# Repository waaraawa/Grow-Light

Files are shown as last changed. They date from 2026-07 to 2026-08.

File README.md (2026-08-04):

# Grow Light

A circular 12 V LED board designed for growing plants. The board uses a single-sided, 80 mm aluminum MCPCB with 20 red LEDs and 3 blue LEDs. A [medium Daiso aluminum makgeolli cup](https://www.daisomall.co.kr/pd/pdr/SCR_PDR_0001?pdNo=58656) serves as the heatsink and mechanical structure.

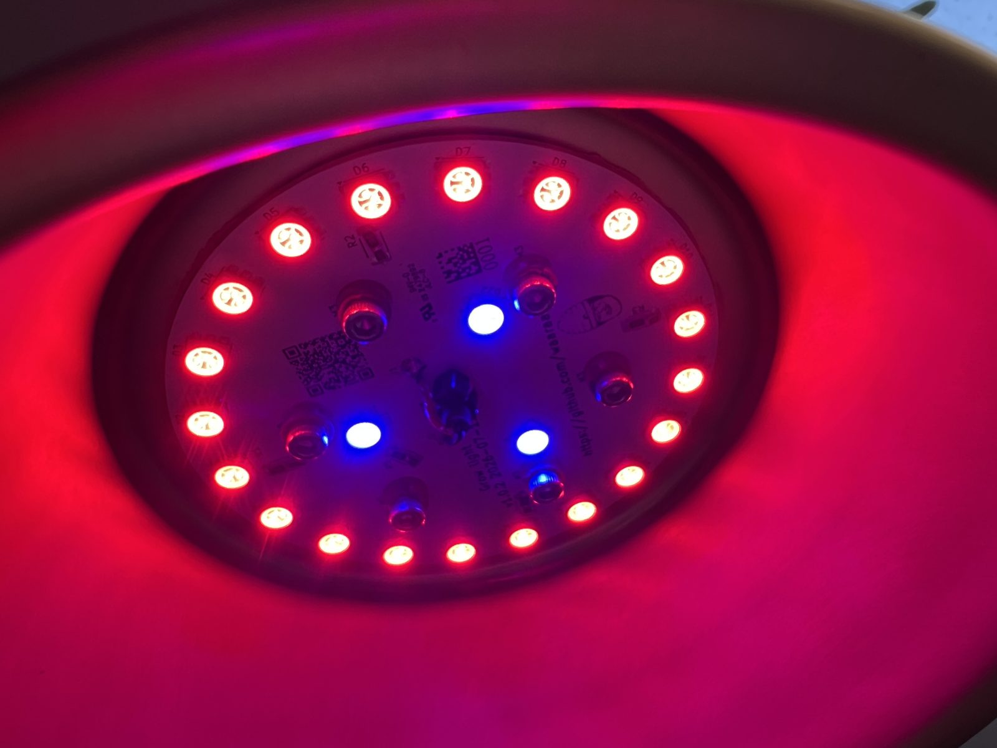
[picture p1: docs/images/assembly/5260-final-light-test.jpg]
Completed Grow Light operating after assembly


## Project Status

- Current KiCad design: `v1.0.3` (`2026-07-27`)
- Manufacturing order version: `v1.0.2` (`2026-07-11`)
- Current phase: `v1.0.2` assembled, functionally tested, and installed
- `v1.0.3` change: added `F.Silkscreen` guides around the six M3 mounting holes and the central cable hole
- Assembly note: the physical `v1.0.2` board currently uses a temporary hand-assembled resistor arrangement pending replacement with correctly sized `5025 Metric (2010 Imperial)` resistors
- DRC: 0 active errors, 0 active warnings, and 0 unconnected pads
- Exclusion: one warning for the unavailable source library of an embedded silkscreen graphic

> The design files in this repository are currently at `v1.0.3`. The previews below and the ordered MCPCB are `v1.0.2`. Manufacturing files for `v1.0.3` have not been generated.

## Specifications

| Item | Specification |
|---|---|
| PCB | 80 mm diameter, 1-layer Aluminum MCPCB |
| PCB thickness | 1.6 mm |
| Copper | 1 oz, `F.Cu` only |
| Surface finish | `HAL SnPb` |
| Solder mask / silkscreen | White / black, front side only |
| Power input | 12 V from a USB-C PD trigger board |
| Target power consumption | Approximately 2 W to 4 W |
| LEDs | 20 red and 3 blue |
| Resistors | Four 68 Ω and one 82 Ω, 2010 package |
| Track widths | 1.2 mm power tracks and 0.6 mm LED interconnects |
| Mounting holes | Six 3.2 mm M3 NPTH holes |
| Cable hole | One central 5.3 mm NPTH hole |

Because KiCad requires an even number of copper layers, the project represents the stackup as a 2-layer board. All electrical copper is on `F.Cu`; `B.Cu` is unused. The actual manufacturing structure is `F.Silkscreen / F.Mask / F.Cu / thermal dielectric / aluminum base`.

## Electrical Configuration

| Channel | LEDs per Series String | Parallel Strings | Total LEDs | String Resistor |
|---|---:|---:|---:|---:|
| Red | 5 | 4 | 20 | 68 Ω |
| Blue | 3 | 1 | 3 | 82 Ω |

The 2010 resistor bodies act as physical jumpers to complete the single-sided routing. Twenty-four `F.Cu` copper zones around the LEDs provide electrical connectivity and local heat spreading. The aluminum core is the primary thermal path, so the design does not use `B.Cu` heat-spreading copper or thermal vias.

## Design Images

### PCB Layout — v1.0.2

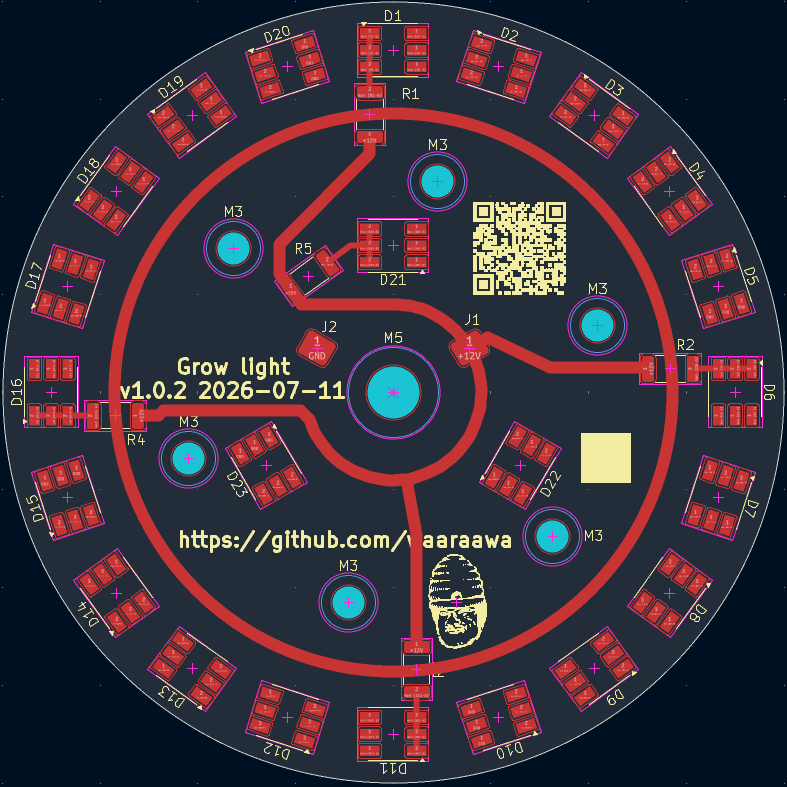
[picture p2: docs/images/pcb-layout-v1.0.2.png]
PCB layout


### Manufacturing Preview — v1.0.2

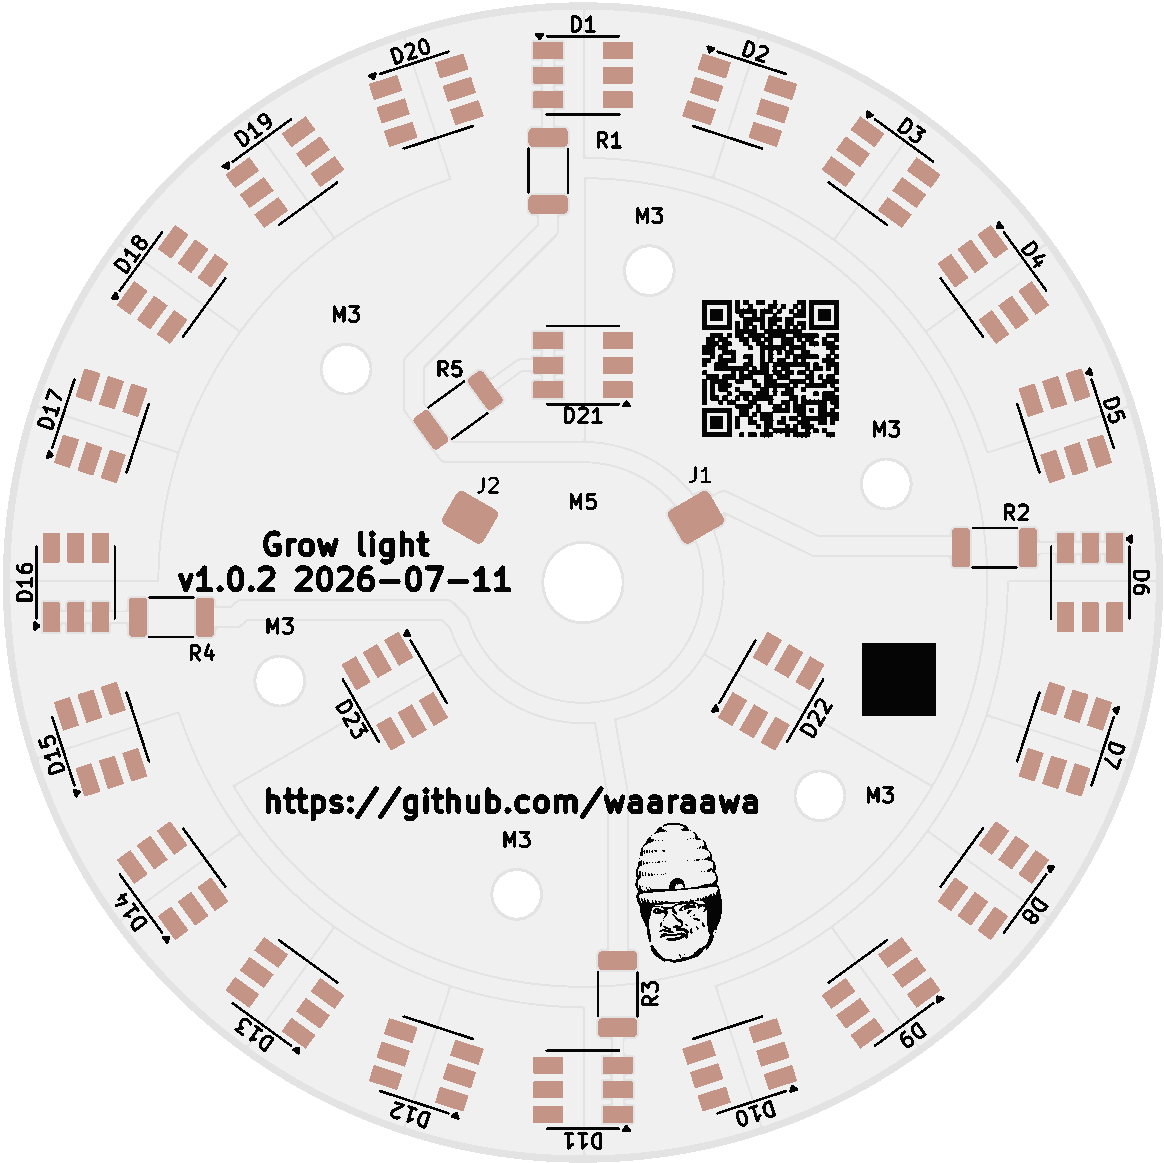
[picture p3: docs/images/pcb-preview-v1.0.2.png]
PCB manufacturing preview


### Assembled Board Preview — v1.0.2

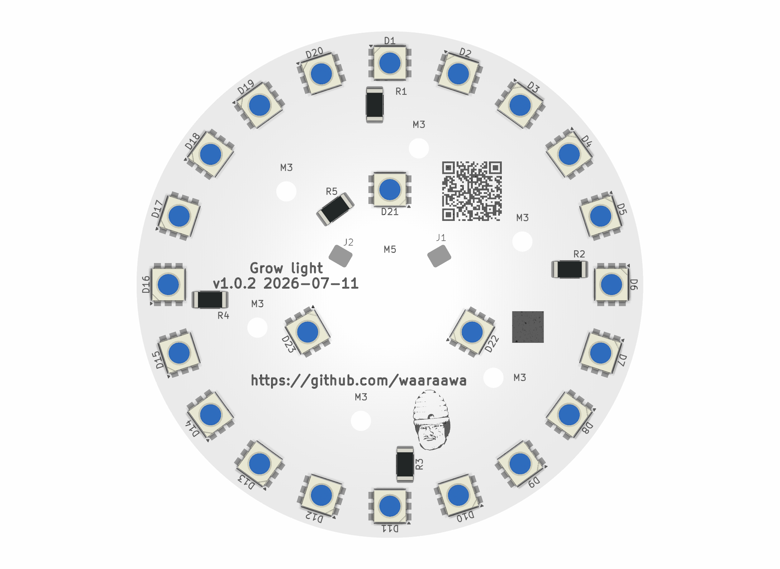
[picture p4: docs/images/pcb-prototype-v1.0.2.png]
Assembled PCB preview


### Manufactured PCB

The physical `v1.0.2` aluminum MCPCB after delivery and initial inspection.

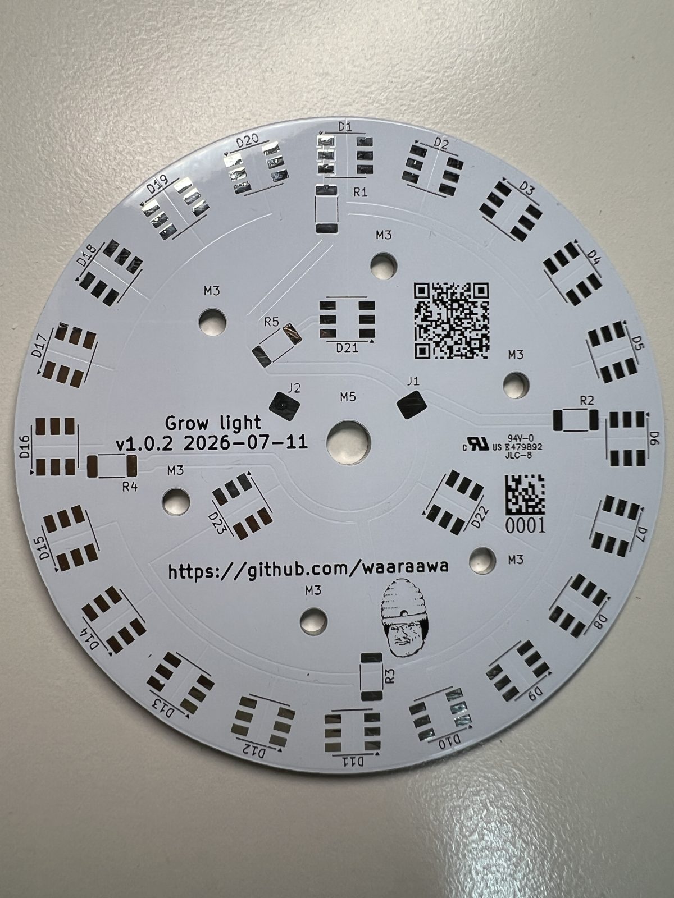
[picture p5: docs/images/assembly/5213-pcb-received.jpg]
Manufactured Grow Light v1.0.2 aluminum MCPCB


### Completed Assembly

The assembled light installed in its intended growing area.

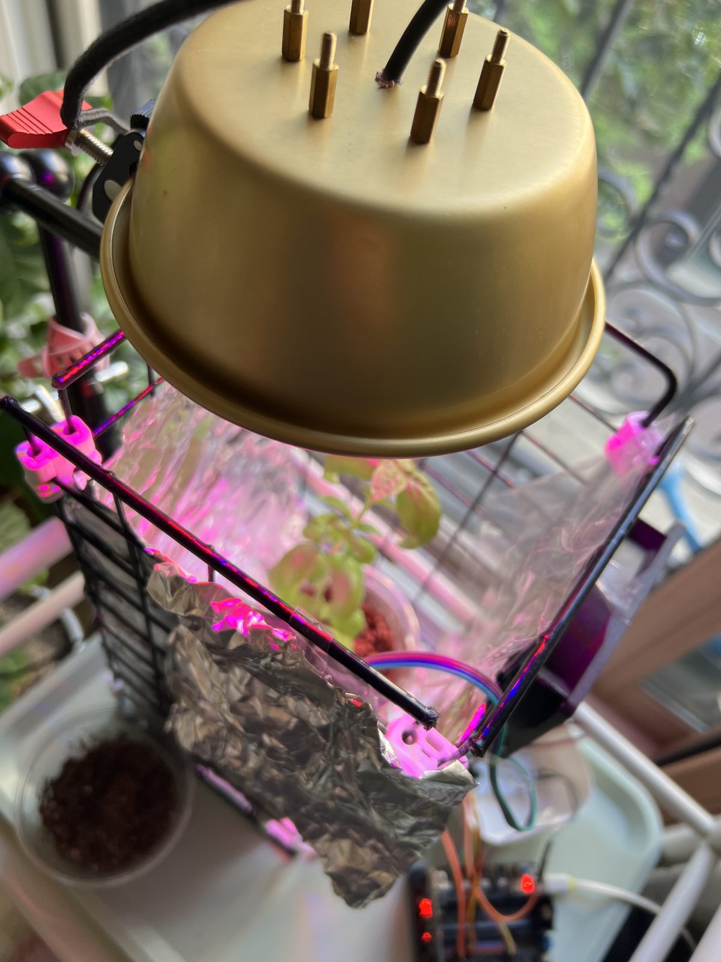
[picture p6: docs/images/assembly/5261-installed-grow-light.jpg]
Completed Grow Light installed in the growing area


See the [`v1.0.2` build log](docs/build-log-v1.0.2.md) for the complete assembly, hot-plate reflow, aluminum-cup drilling, thermal-interface, testing, and installation process.

## Assembly and Safety

- The red `IWS-L5056-UR-N3` and blue `IWS-L5056-UB-K3` LEDs use opposite footprint polarities. Verify every LED before placement.
- Do not rely on cable colors. Measure the 12 V output and polarity with a multimeter before soldering the cable to `J1 +12V` and `J2 GND`.
- Fit a grommet or strain relief where the cable passes through the central hole.
- Apply electrically non-conductive `UPSIREN UTP-8` in a thin, even layer between the PCB and the aluminum cup.
- Use insulating washers or nylon shoulder washers at the M3 mounting points.
- Before applying power and again after final assembly, verify that the aluminum structure and fasteners are not shorted to `+12V` or `GND`.
- The aluminum structure and external bracket, rather than the PCB, must carry the lamp's mechanical load.

## Repository Contents

- [`plant led.kicad_sch`](plant%20led.kicad_sch): schematic
- [`plant led.kicad_pcb`](plant%20led.kicad_pcb): PCB layout
- [`plant led.kicad_pro`](plant%20led.kicad_pro): KiCad project settings
- [`parts_list.md`](parts_list.md): parts, manufacturing, and assembly specifications
- [`to-do.md`](to-do.md): production, assembly, and test status
- [`docs/build-log-v1.0.2.md`](docs/build-log-v1.0.2.md): physical `v1.0.2` manufacturing, assembly, and installation log
- [`references/datasheets`](references/datasheets): LED datasheets

Manufacturing Gerber files are not included in the repository. The `footprints:` library is also stored in an external directory shared by multiple projects. To open the project in another environment, configure the same shared library path.

## License

This project is licensed under the [MIT License](LICENSE).

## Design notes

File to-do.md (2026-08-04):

# Plant LED PCB Status and To-Do

## To-Do

The next step is to prepare the components and assembly equipment.

### 4. Parts and Assembly Preparation

- [ ] Prepare the LEDs, resistors, and spare parts listed in `parts_list.md`.
- [ ] Prepare solder paste compatible with the MCPCB and components.
- [ ] Prepare a PTC hot plate capable of heating the 80 mm MCPCB evenly.
- [ ] Set the USB-C PD trigger board to 12 V and verify the actual output with a multimeter.
- [ ] Prepare an approximately 4 mm outer-diameter power cable and a grommet or strain relief for the center hole.
- [ ] Prepare six each of the M3 screws, nuts, washers, and insulating shoulder washers.
- [ ] Prepare `UPSIREN UTP-8` and any additional insulating film required.

### 5. MCPCB Assembly

1. Inspect the received MCPCB outline, pads, solder mask, silkscreen, and hole positions.
2. Use a multimeter to check for a short between `+12V` and `GND`.
3. Verify the different polarities of the red and blue LEDs.
4. Apply a thin, uniform layer of solder paste.
5. Place the LEDs and resistors, then inspect their positions and polarities under magnification.
6. Heat the board on the PTC hot plate and inspect every solder joint.
7. Pass the cable through the central 5.3 mm hole and apply strain relief.
8. Measure the cable polarity, then solder it to `J1 +12V` and `J2 GND`.
9. Recheck polarity, shorts, and solder bridges before applying power.
10. Apply power briefly and confirm that every LED string illuminates normally.
11. Apply `UPSIREN UTP-8` in a thin, uniform layer and tighten the six M3 screws evenly.
12. After final fastening, verify isolation between the aluminum cup and fasteners and both `+12V` and `GND`.

### 6. Operating Verification and Results

- [ ] Replace the temporary hand-assembled `2012 Metric (0805 Imperial)` and `3216 Metric (1206 Imperial)` `1R0` resistor combinations with correctly sized `5025 Metric (2010 Imperial)` resistors.
- [ ] Measure the input voltage and total current at first power-on.
- [ ] Verify the illumination of each of the four red strings and the one blue string.
- [ ] Record the current temporary configuration as the thermal baseline. The initial observation was an indoor ambient temperature of approximately 30 °C and a lamp temperature no higher than 34 °C, corresponding to a temperature rise of no more than approximately 4 °C.
- [ ] Measure the MCPCB and aluminum cup temperatures after 10 and 15 minutes.
- [ ] Check the PD trigger board and cable temperatures during extended operation.
- [ ] Test alternative resistor values one configuration at a time, recording input current and temperatures for each test.
- [ ] If the temperature remains acceptable, evaluate whether lower resistor values can safely provide the desired output. If the temperature becomes excessive, increase the resistor values or reduce the supply power.
- [ ] Record actual current, temperature, assembly issues, and improvements in the table below.

| Item | Initial Power-On | 10 Minutes | 15 Minutes | Notes |
|---|---:|---:|---:|---|
| Ambient temperature |  |  |  |  |
| Input voltage |  |  |  |  |
| Total current |  |  |  |  |
| MCPCB temperature |  |  |  |  |
| Aluminum cup temperature |  |  |  |  |
| Temperature rise above ambient |  |  |  |  |
| PD trigger board temperature |  |  |  |  |

### Future Improvement Candidates

- [ ] Finalize and document the production resistor values based on the measured current and temperature results.
- [ ] If diffuser lenses are used, verify the 8 mm x 8 mm clearance and actual mechanical interference.
- [ ] Verify the long-term durability of the cable grommet and external bracket.

## Current Status

- Current phase: `MCPCB ordered / awaiting production and delivery`
- Manufacturing type: `1-layer Aluminum MCPCB`
- Current KiCad design: `v1.0.3` (`2026-07-27`)
- Manufacturing order version: `v1.0.2` (`2026-07-11`)
- Board outline: 80 mm diameter circle
- Power: 12 V USB-C PD trigger board
- LED configuration: 20 red LEDs and 3 blue LEDs
- Routing: all components, tracks, and copper zones on `F.Cu`
- Mechanical enclosure: Daiso medium aluminum makgeolli cup
- Final ordered Gerber: `gerber/grow light gerber 1.0.2 2026-0711.zip`
- DRC: 0 active errors, 0 active warnings, and 1 graphic-related exclusion

The medium aluminum cup was evaluated first, and the board design began after selecting an 80 mm diameter. The `v1.0.2` Gerber manufacturing files were inspected and used to order the MCPCB. The current `v1.0.3` KiCad design adds silkscreen guides around the mounting and cable holes but has not been released as a manufacturing package. There are no active DRC errors or warnings; the only exclusion is for the unavailable library source of a board-embedded silkscreen graphic.

## Completed History

### 2026-07-27 — v1.0.3 Silkscreen and Documentation Update

- [x] Added `F.Silkscreen` guides around the six M3 mounting holes.
- [x] Added an `F.Silkscreen` guide around the central 5.3 mm cable hole.
- [x] Updated the board silkscreen version and date to `v1.0.3 2026-07-27`.
- [x] Reran `Inspect -> Design Rules Checker` and confirmed 0 active errors, 0 active warnings, and 0 unconnected pads.
- [x] Added the project README and `v1.0.2` design preview images.
- [x] Documented the direct Aluminum MCPCB production direction and the aluminum cup product reference.

### 2026-07-13 — Stackup, DRC, and Order Status Finalized

- [x] Kept KiCad's 2-layer representation because of its even-copper-layer requirement, while using only `F.Cu` as real copper.
- [x] Recorded Aluminum MCPCB, 1.6 mm overall thickness, 0.035 mm `F.Cu`, `HAL SnPb`, white `F.Mask`, and black `F.Silkscreen` in the stackup metadata.
- [x] Decided to share the `footprints:` library from a common directory rather than duplicating it in the project.
- [x] Reran `Inspect -> Design Rules Checker` and confirmed that there were no errors.
- [x] Reviewed the warning for the board-embedded silkscreen graphic whose `Symbol:mark` library source was unavailable and excluded it with a comment as an intentional exception.
- [x] Finalized the board outline and hole positions based on the medium aluminum cup evaluation.
- [x] Approved `v1.0.2` as the final manufacturing release.
- [x] Inspected the outline, LED pads, power pads, solder mask, silkscreen, and NPTH data in a Gerber viewer.
- [x] Confirmed that the ZIP contains `F.Cu`, `F.Mask`, `F.Silkscreen`, `Edge.Cuts`, and the NPTH drill file.
- [x] Verified the six 3.2 mm NPTH holes and the central 5.3 mm NPTH hole.
- [x] Confirmed that the design does not require plated through holes.
- [x] Confirmed the 1-layer Aluminum MCPCB, 80 mm outline, and manufacturing specifications with the manufacturer.
- [x] Confirmed that the manufacturer supports the 0.6 mm minimum track width and the current copper clearances.
- [x] Ordered the MCPCB using the final `v1.0.2` manufacturing ZIP.

For any future PCB design or manufacturing-file change, increment the version and silkscreen date and create a new manufacturing ZIP.

### 2026-07-13 — Repository and Documentation Cleanup

- [x] Established the main `plant led.*` project files as the current source of truth.
- [x] Deleted the `wrong_via` variant and Dropbox conflict copies.
- [x] Standardized the project instruction filename as `AGENTS.md`.
- [x] Moved datasheets into `references/datasheets/`.
- [x] Moved reference images into `references/images/` and cleaned up their filenames.
- [x] Moved the QR source into `assets/qr.svg`.
- [x] Updated the mechanical enclosure from the Daiso small aluminum makgeolli cup to the medium size and reflected the change in the documentation.

### 2026-07-11 — v1.0.2 Design and Manufacturing Files

- [x] Finalized the 12 V supply and red-heavy LED configuration.
- [x] Configured the red channel as four parallel strings of five LEDs, with one 68 ohm resistor per string.
- [x] Configured the blue channel as one string of three LEDs with an 82 ohm resistor.
- [x] Placed 20 red LEDs and 3 blue LEDs on the circular 80 mm board.
- [x] Placed all components, tracks, and copper zones on `F.Cu`.
- [x] Applied 1.2 mm power tracks and 0.6 mm LED interconnect tracks.
- [x] Used the 2010 resistor bodies as physical jumpers to complete the 1-layer routing.
- [x] Added 24 `F.Cu` copper zones around the LEDs.
- [x] Placed six 3.2 mm M3 NPTH holes at a radius of approximately 22 mm from the board center.
- [x] Added a central 5.3 mm NPTH cable pass-through hole.
- [x] Added the `v1.0.2 2026-07-11` silkscreen marking.
- [x] Generated the `v1.0.2` Gerber ZIP.

### Before Development — Mechanical Verification and Manufacturing Direction

- [x] Measured the medium aluminum makgeolli cup before selecting the PCB size.
- [x] Selected an 80 mm PCB diameter based on the measurements.
- [x] Verified the mechanical fit of the 80 mm PCB with the cup.
- [x] Checked the six M3 holes and central cable hole for interference with the cup geometry.
- [x] Checked the available contact area between the PCB and cup.
- [x] Reviewed the external bracket and M3 fastening structure.
- [x] Confirmed direct production as a 1-layer Aluminum MCPCB.
- [x] Confirmed that the design would not use `B.Cu` copper or thermal vias.

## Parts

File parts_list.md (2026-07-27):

# Plant LED PCB Parts and Manufacturing Specification

## Current Design Summary

- Current KiCad design: `v1.0.3` (`2026-07-27`)
- Manufacturing order version: `v1.0.2` (`2026-07-11`)
- Manufacturing direction: Direct production as a `1-layer Aluminum MCPCB`
- Board outline: 80 mm diameter circle
- Power input: 12 V from a USB-C PD trigger board
- Available supply: 12 V, up to approximately 1.5 A
- Target board power: approximately 2 W to 4 W
- LED configuration: 20 red LEDs and 3 blue LEDs
- Copper usage: all components, tracks, and zones on `F.Cu`; no `B.Cu` copper or thermal vias
- Mechanical holes: six 3.2 mm M3 NPTH holes and one central 5.3 mm NPTH cable pass-through hole
- Latest manufacturing package: `gerber/grow light gerber 1.0.2 2026-0711.zip`

## v1.0.2 Order Specification

| Item | Ordered Value |
|---|---|
| Quantity | 5 boards |
| Base Material | Aluminum |
| Layers | 1 |
| Dimension | 80 mm x 80 mm |
| PCB Thickness | 1.6 mm |
| Specify Stackup | No |
| Outer Copper Weight | 1 oz |
| Solder Mask | White, front only |
| Silkscreen | Black, front only |
| Surface Finish | HASL with lead (`HAL SnPb`) |
| Back Copper | None |
| Thermal Conductivity | 1 W/(m·K) |
| Breakdown Voltage | 3000 V |
| Electrical Test | Not tested |
| Appearance Quality | IPC Class 2 Standard |

## Electrical Configuration

| Channel | LEDs per Series String | Parallel Strings | Total LEDs | Resistor per String | Notes |
|---|---:|---:|---:|---:|---|
| Red | 5 | 4 | 20 | 68 ohm | Conservative configuration for 12 V utilization and thermal control |
| Blue | 3 | 1 | 3 | 82 ohm | Provides margin for the LED forward voltage |

## PCB-Mounted Parts

| References | Part | Quantity | Current Specification | Notes |
|---|---|---:|---|---|
| D1-D20 | Red SMD LED | 20 | ITSWELL `IWS-L5056-UR-N3` | 5050, 650-665 nm, Vf 1.8-2.4 V @ 60 mA |
| D21-D23 | Blue SMD LED | 3 | ITSWELL `IWS-L5056-UB-K3` | 5050, 450-475 nm, Vf 2.8-3.6 V @ 60 mA |
| R1-R4 | Red string resistor | 4 | 68 ohm, 2010, 0.75 W or higher recommended | One per string |
| R5 | Blue string resistor | 1 | 82 ohm, 2010, 0.75 W or higher recommended | One per string |
| J1 | `+12V` input pad | 1 | 3.2 mm x 2.6 mm front SMD solder pad | No through-hole connector |
| J2 | `GND` input pad | 1 | 3.2 mm x 2.6 mm front SMD solder pad | No through-hole connector |
| PCB1 | LED PCB | 1 | 80 mm diameter, 1-layer Aluminum MCPCB | All electrical copper is on `F.Cu` |

## Current PCB Routing and Copper

- `F.Cu` power-track width: 1.2 mm
- Selected LED series-connection track width: 0.6 mm
- `F.Cu` copper zones: 24
- The single-sided routing is completed with a combination of conventional tracks and copper zones.
- The 2010 resistor bodies act as physical jumpers to avoid routing crossings on the 1-layer board.
- `F.Cu` copper around the LEDs provides both electrical connectivity and local heat spreading.
- There are no `B.Cu` tracks or zones.
- Thermal vias are not used. Heat transfers through the MCPCB dielectric layer into the aluminum core.
- The latest Gerber package contains `F.Cu`, `F.Mask`, `F.Silkscreen`, `Edge.Cuts`, and NPTH drill data.
- There are no plated through holes, and the current `PTH.drl` contains no drill coordinates.

## PCB Manufacturing and Assembly Equipment

| Item | Quantity | Recommended Specification | Notes |
|---|---:|---|---|
| Solder paste | 1 | Compatible with the LED and resistor pads | Apply a thin, uniform layer |
| PTC hot plate | 1 | Large enough to heat the complete MCPCB evenly | For LED and resistor reflow assembly |
| Tweezers | 1 | Precision SMD type | Verify LED polarity before placement |
| Multimeter | 1 | Voltage, resistance, and continuity measurement | Verify PD output, polarity, and isolation |
| USB-C PD trigger board | 1 | Low-voltage model selectable among 5/9/12/15/20 V | Set to 12 V and verify by measurement |
| USB-C PD power source | 1 | Supports 12 V at 1.5 A or more | Maximum available input is approximately 18 W |
| Power cable | 1 | Reused USB cable, approximately 4 mm outer diameter | Measure polarity instead of relying on conductor colors |

## Mechanical and Thermal Parts

| Item | Quantity | Recommended Specification | Notes |
|---|---:|---|---|
| Aluminum cup | 1 | [Daiso medium aluminum makgeolli cup](https://www.daisomall.co.kr/pd/pdr/SCR_PDR_0001?pdNo=58656) | Verify the actual contact area with the 80 mm PCB |
| Thermal interface | 1 | Electrically non-conductive `UPSIREN UTP-8` | Compress into a thin, uniform layer |
| M3 fastener sets | 6 | M3 screws, washers, and nuts | Corresponding to the six 3.2 mm NPTH holes |
| M3 insulation parts | 6 | Nylon shoulder washers or insulating washers | Prevent contact between fasteners and PCB copper |
| Insulating film | As needed | Kapton or PET film | Additional insulation where required |
| Cable grommet | 1 | Fits the 5.3 mm center hole and approximately 4 mm cable | Protects cable insulation and provides strain relief |
| External mounting arm | 1 | Small clamp and 1/4 inch magic arm | Keep as short as practical to reduce torque |
| External adapter plate | 1 | Transfers load into the aluminum cup | Prevent the PCB from carrying the lamp support load |
| Optional diffuser lenses | 23 | 8 mm x 8 mm lenses for 5050 LEDs | Check mechanical interference around each LED |

## Recommended Spare Parts

| Part | Recommended Spare Quantity | Purpose |
|---|---:|---|
| Red LED | 5-10 | Assembly failures and component variation |
| Blue LED | 3-5 | Assembly failures |
| 56 ohm resistor | 5 | Higher-current experiments |
| 68 ohm resistor | 10 | Default red value and replacements |
| 82 ohm resistor | 5 | Default blue value and replacements |
| 100 ohm resistor | 5 | Tests with lower current and heat |

## Polarity and Safety Checks

1. Verify the PD trigger board's 12 V setting and actual output voltage before connecting it to the LED PCB.
2. Identify `+12V` and `GND` with a multimeter rather than relying on cable insulation colors.
3. Verify the different footprint polarities of `IWS-L5056-UR-N3` and `IWS-L5056-UB-K3`.
4. Check for a short between `+12V` and `GND` before applying power after assembly.
5. After final fastening, confirm that the aluminum cup and fasteners are not shorted to `+12V` or `GND`.
6. Apply power briefly at first and verify the total current and illumination of every string.
7. After 10 to 15 minutes of operation, check the temperatures of the MCPCB and aluminum cup.
8. If the temperature is excessive, increase the resistor values or reduce the supply power.

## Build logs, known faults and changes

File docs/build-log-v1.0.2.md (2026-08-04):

# Grow Light v1.0.2 Build Log

This document records the manufacturing, assembly, testing, and installation of the physical `v1.0.2` Grow Light board. The current KiCad design may contain changes made after this board was manufactured.

## 1. PCB Delivery and Inspection

The aluminum MCPCB was received from JLCPCB.

Grow Light v1.0.2 board received from JLCPCB

During inspection, a few areas were found where the white surface resin coating had peeled away and exposed the copper underneath. The board was still considered usable. Protective resin will be applied to these areas later.

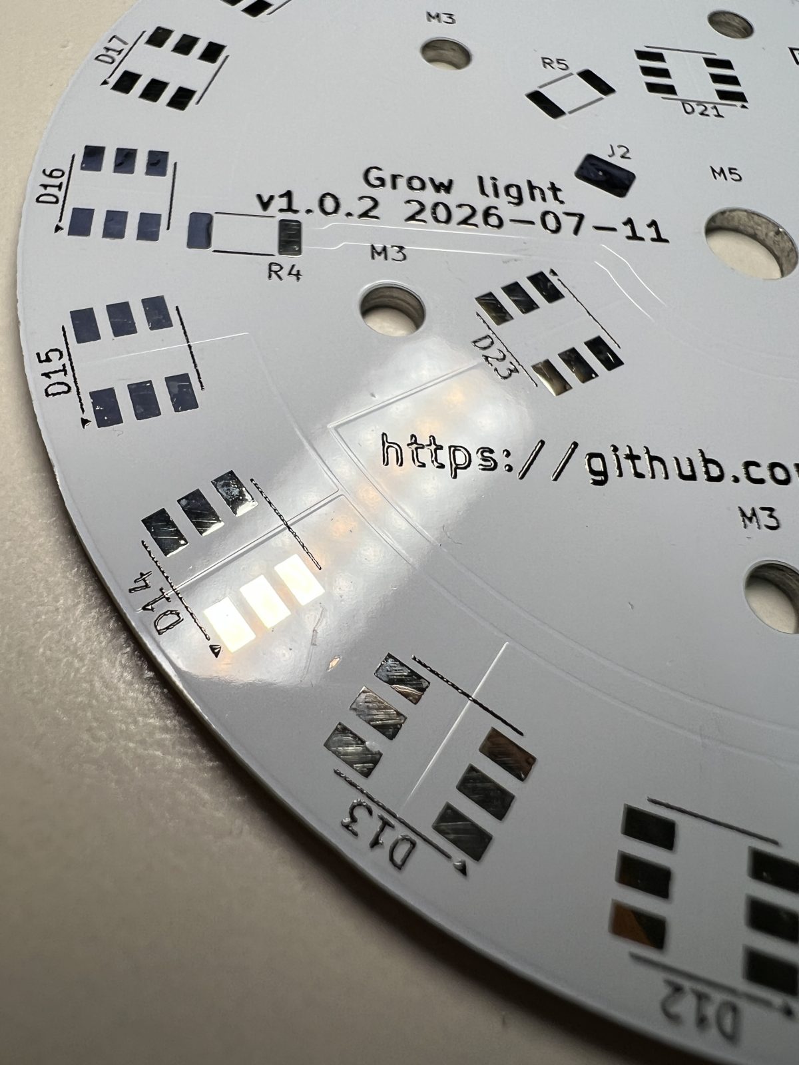
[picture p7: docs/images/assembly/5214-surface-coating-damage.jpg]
Area with exposed copper caused by peeled surface resin


## 2. Solder Paste Application

Solder paste was applied to the PCB pads using a watch oiler as a fine dispensing tool.

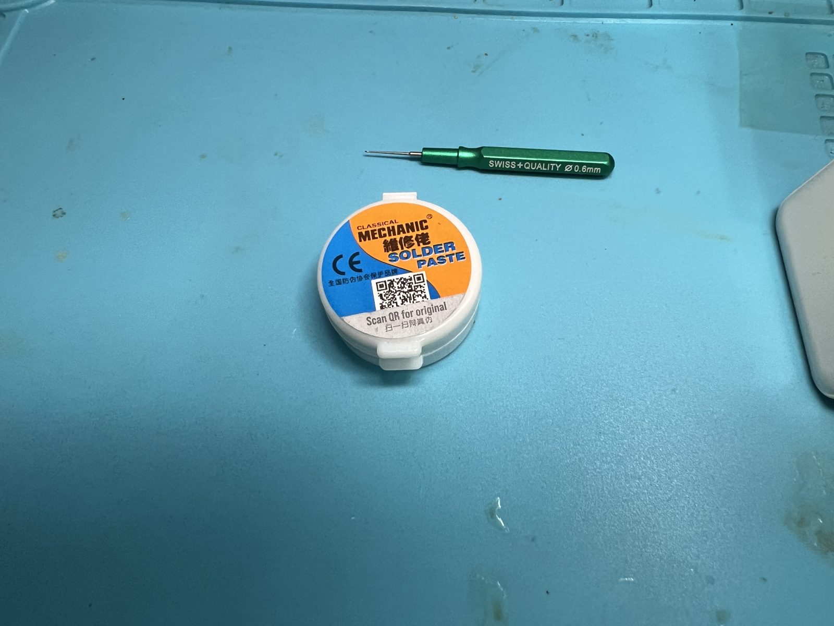
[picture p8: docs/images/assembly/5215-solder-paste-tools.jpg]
Solder paste and watch oiler used for application


After application, the solder paste covered the LED and resistor pads in preparation for component placement.

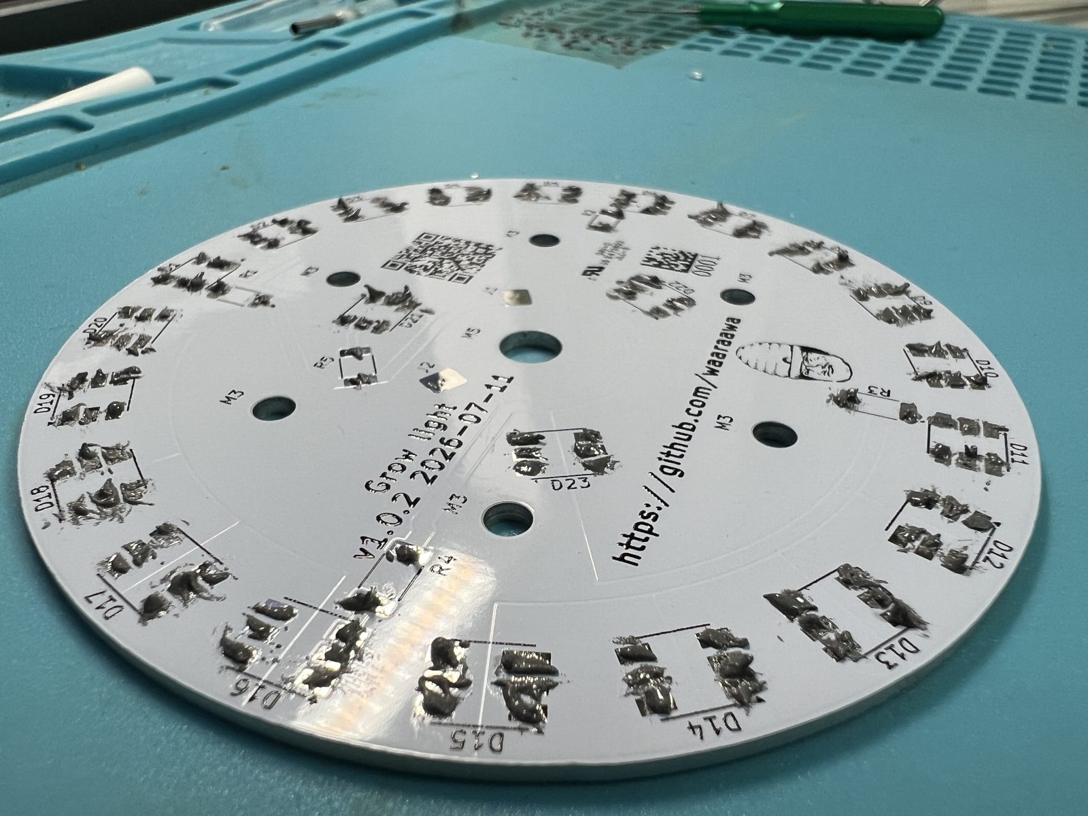
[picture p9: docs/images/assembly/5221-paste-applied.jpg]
PCB after solder paste application


## 3. LED Placement and Hot-Plate Reflow

The LEDs were placed on the pasted pads, and the board was positioned on the hot plate.

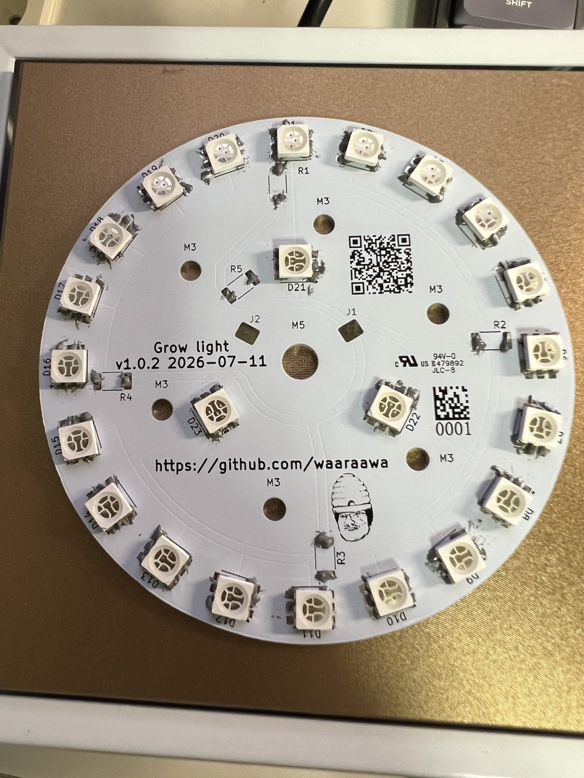
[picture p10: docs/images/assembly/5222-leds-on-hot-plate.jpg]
LEDs placed on the PCB before hot-plate reflow


At this stage, the resistor footprints were still empty. It was discovered during component placement that the resistors on hand were `2012 Metric (0805 Imperial)`, which had been mistaken for the required `5025 Metric (2010 Imperial)` package. The available resistors therefore did not match the intended PCB footprints.

The hot plate was first heated to approximately 120 °C. At this temperature, the solder paste began to soften and form rounded deposits.

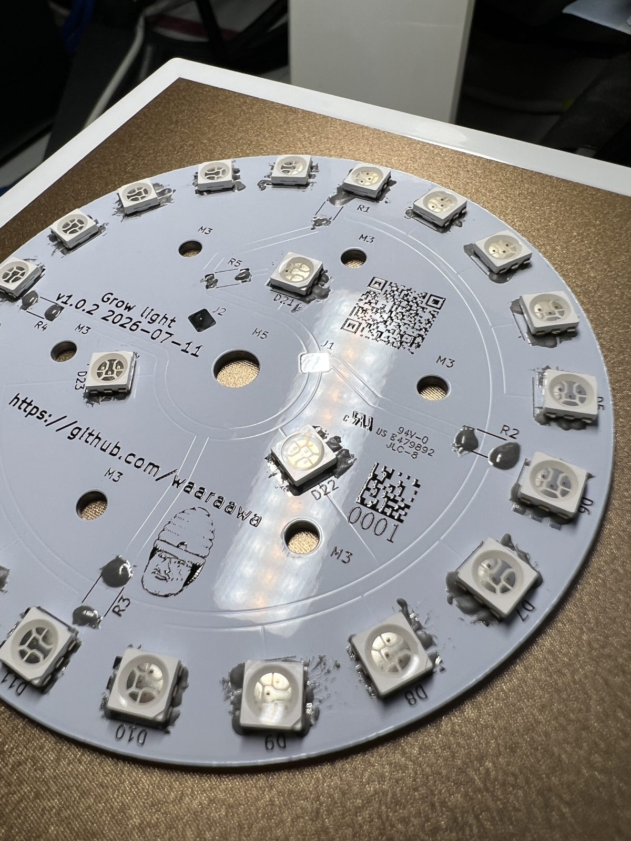
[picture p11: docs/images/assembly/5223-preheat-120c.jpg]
Solder paste beginning to soften at approximately 120 degrees Celsius


The temperature was then raised to approximately 220 °C to complete the soldering process.

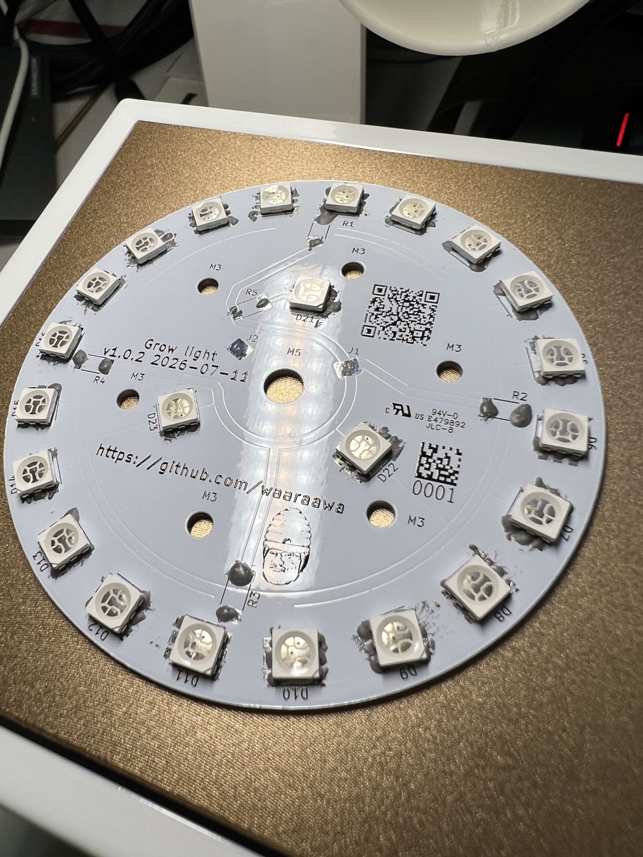
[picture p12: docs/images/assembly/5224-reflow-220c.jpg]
PCB after reflow at approximately 220 degrees Celsius


A temporary resistor arrangement was assembled by hand so that the board could be powered and functionally tested. At each affected footprint, the available `2012 Metric (0805 Imperial)` resistor was combined in series with a `3216 Metric (1206 Imperial)` `1R0` resistor. The two components were manually positioned end-to-end across the larger `5025 Metric (2010 Imperial)` land pattern. This arrangement physically bridged the intended footprint while adding 1 Ω to the resistance of each temporary path.

This hand-assembled configuration is only a temporary workaround for initial operation and testing. It will later be replaced with a single resistor of the correct value in the intended `5025 Metric (2010 Imperial)` package.

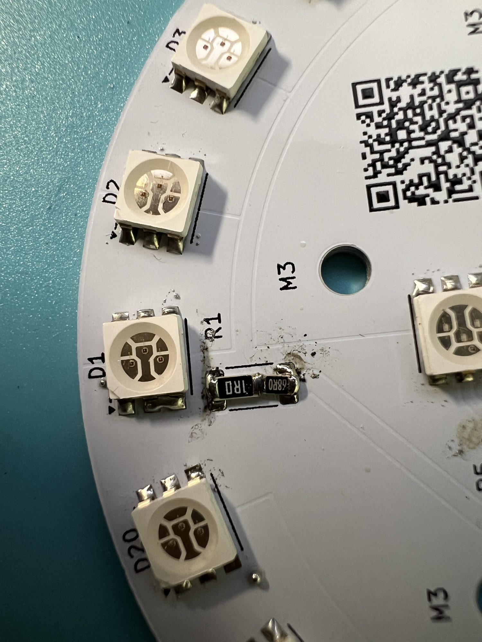
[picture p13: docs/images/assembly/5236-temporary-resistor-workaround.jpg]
Temporary resistor arrangement used for functional testing


## 4. Cleanup and Functional Test

After the board surface was cleaned, power was applied to verify operation. All red and blue LED channels illuminated during the test.

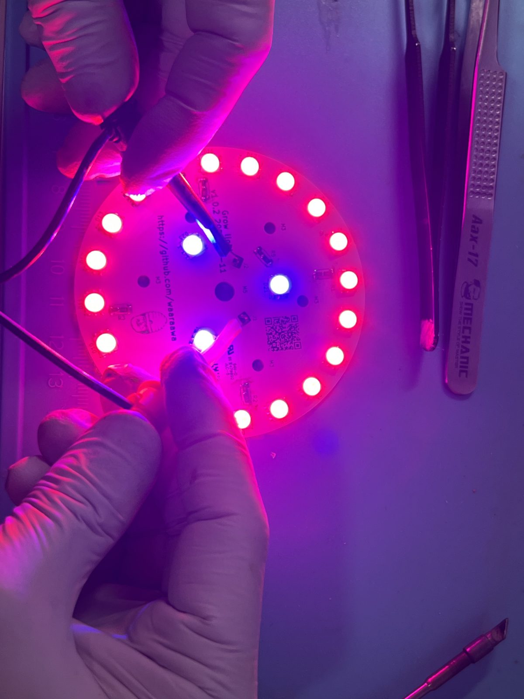
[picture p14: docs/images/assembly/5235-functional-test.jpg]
Functional test after cleaning the assembled PCB


## 5. Aluminum Cup Hole Layout

The mounting-hole positions were checked before drilling the aluminum makgeolli cup. The center hole was based on the M5 cable opening, and the six surrounding M3 mounting holes were positioned at a radius of 22 mm from the center.

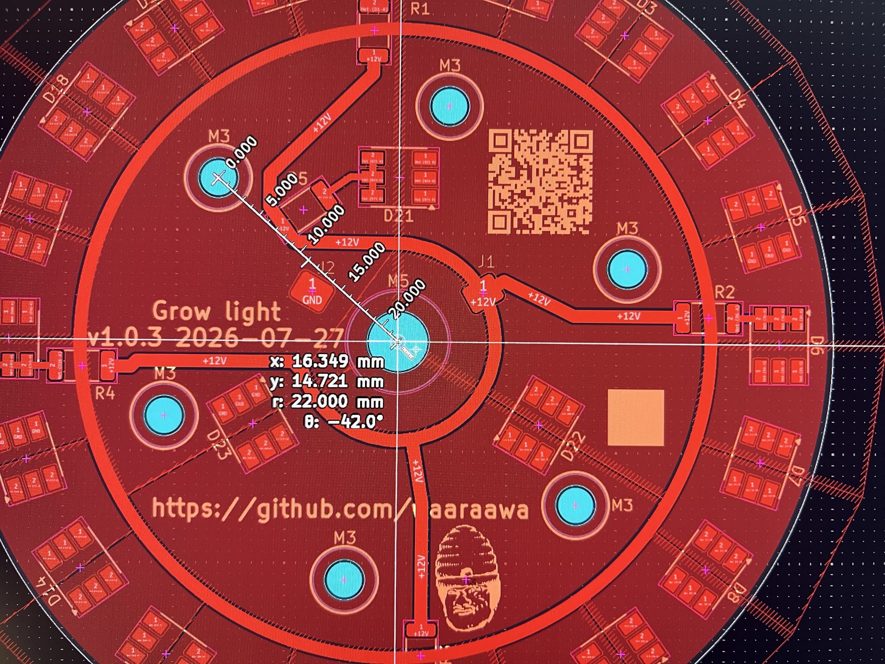
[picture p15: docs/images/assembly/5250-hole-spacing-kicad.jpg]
Checking the mounting-hole spacing in KiCad


The hole pattern was then drawn on the aluminum cup.

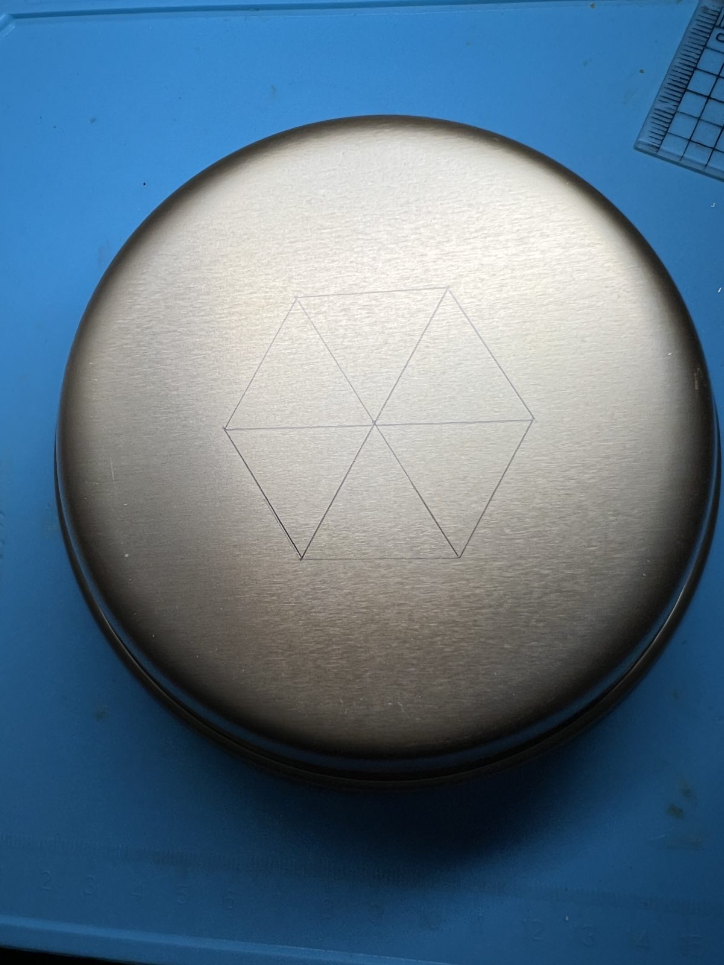
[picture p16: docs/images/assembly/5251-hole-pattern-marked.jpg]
Hole pattern marked on the aluminum cup


Small indentations were made at the marked positions to keep the drill bit from wandering.

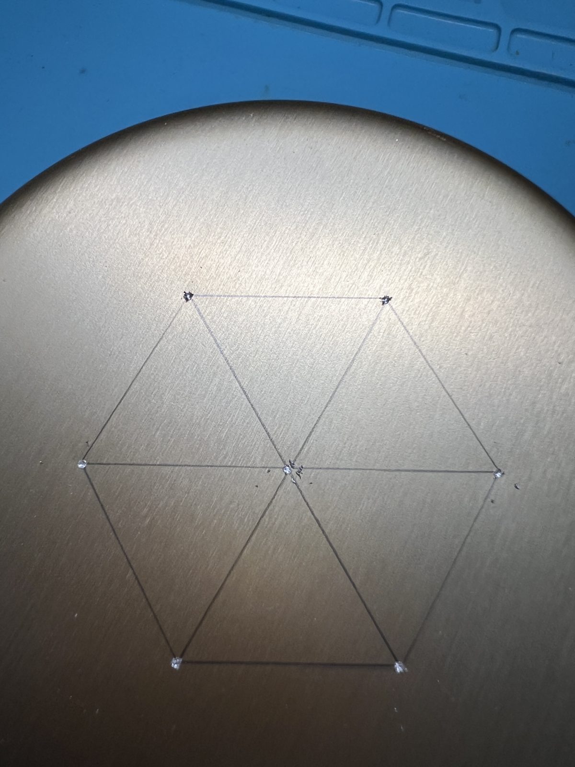
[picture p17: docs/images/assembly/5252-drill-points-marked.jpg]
Drilling positions marked with small indentations


One drop of cutting oil was applied before drilling.

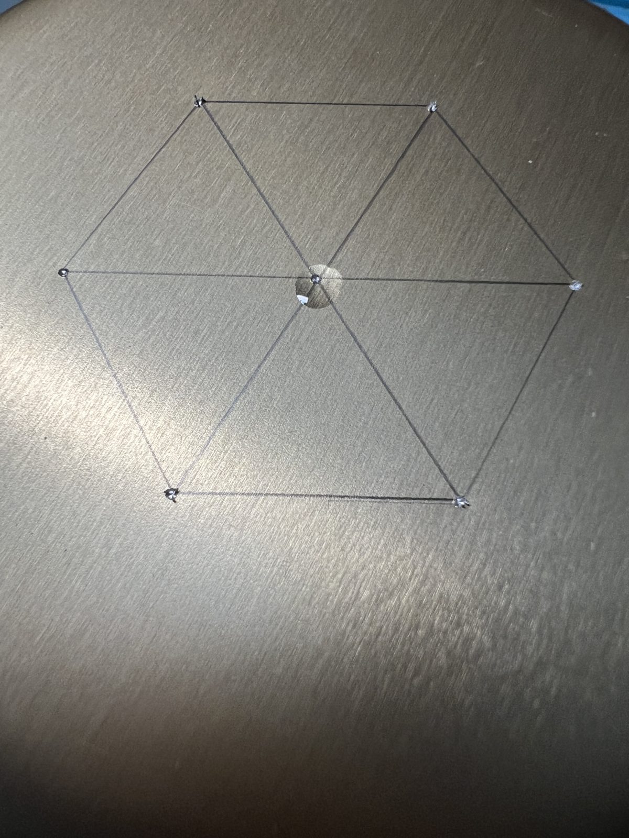
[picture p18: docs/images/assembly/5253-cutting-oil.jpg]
Cutting oil applied at the drilling position


The center M5 hole was drilled first.

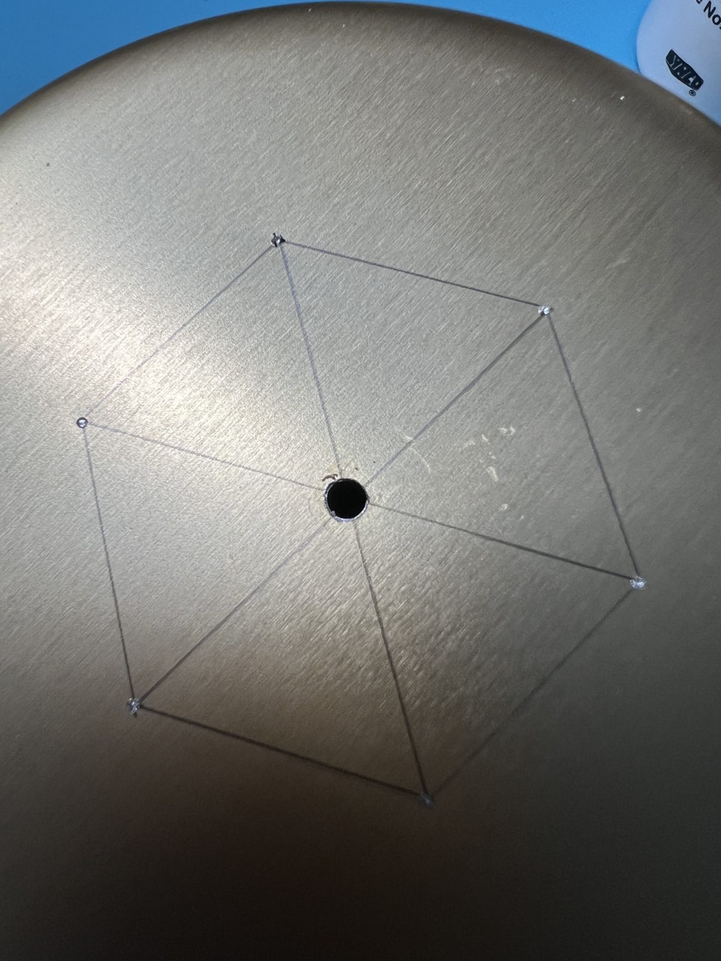
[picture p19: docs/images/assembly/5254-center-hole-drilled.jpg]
Center M5 hole after drilling


The remaining six M3 mounting holes were then drilled.

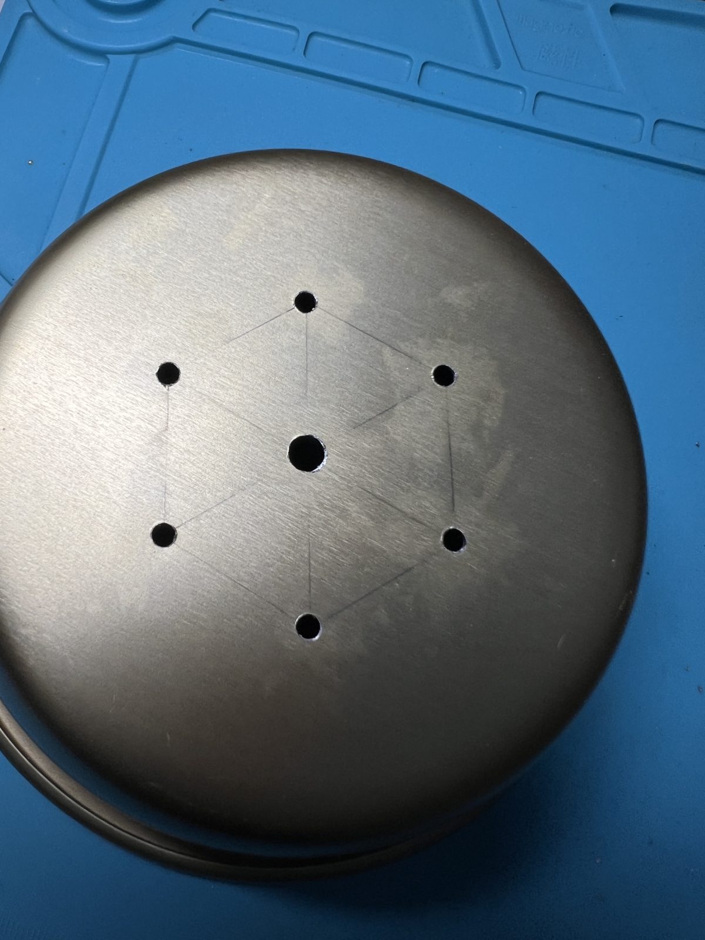
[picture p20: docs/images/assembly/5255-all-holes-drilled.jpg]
Aluminum cup after all holes were drilled


The completed hole pattern was checked against the PCB. There was a small amount of positional error, but the board and cup could still be assembled without redrilling the holes.

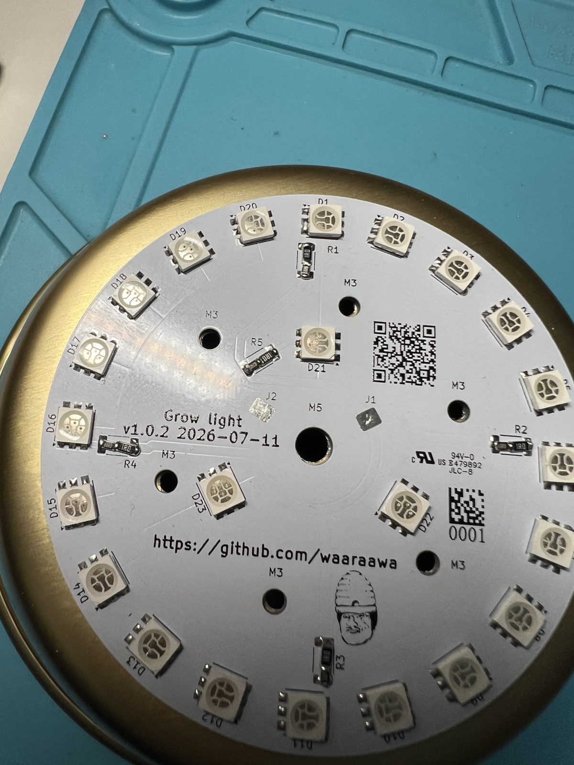
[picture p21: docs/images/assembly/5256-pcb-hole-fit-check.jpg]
Checking the drilled holes against the PCB


## 6. Thermal Interface Application

Thermal paste was applied between the aluminum MCPCB and the aluminum cup. Because the paste did not spread easily across the metal surface, it was later rolled into long strips, placed around the drilled holes, and compressed during assembly so that it could spread into a thin contact layer.

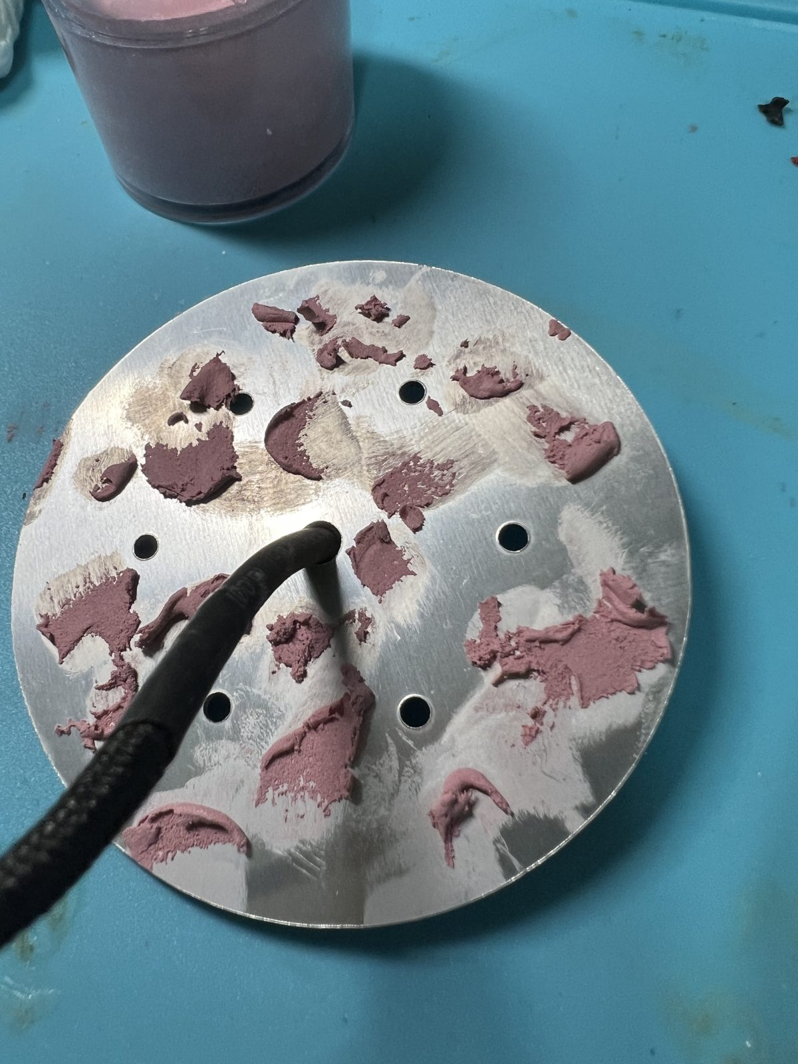
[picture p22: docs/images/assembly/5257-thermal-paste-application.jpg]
Applying thermal paste to the back of the MCPCB


## 7. Final Assembly and Installation

After assembly, the completed light was powered on and tested again.

Grow Light operating after final assembly

The light was then installed in its intended growing area and powered on for normal use.

Grow Light powered on after installation

## 8. Follow-up Work Identified After Assembly

- Replace the hand-assembled temporary resistor combinations with correctly sized `5025 Metric (2010 Imperial)` resistors.
- Re-evaluate the resistor values. The initial values may have been calculated too conservatively, so different resistor values should be tested while monitoring heat generation before selecting the final configuration.
- During the current preliminary observation, the lamp temperature did not exceed 34 °C even when the indoor ambient temperature was approximately 30 °C. This corresponds to a temperature rise of no more than approximately 4 °C under the observed conditions. Additional temperature testing with alternative resistor values is still required.

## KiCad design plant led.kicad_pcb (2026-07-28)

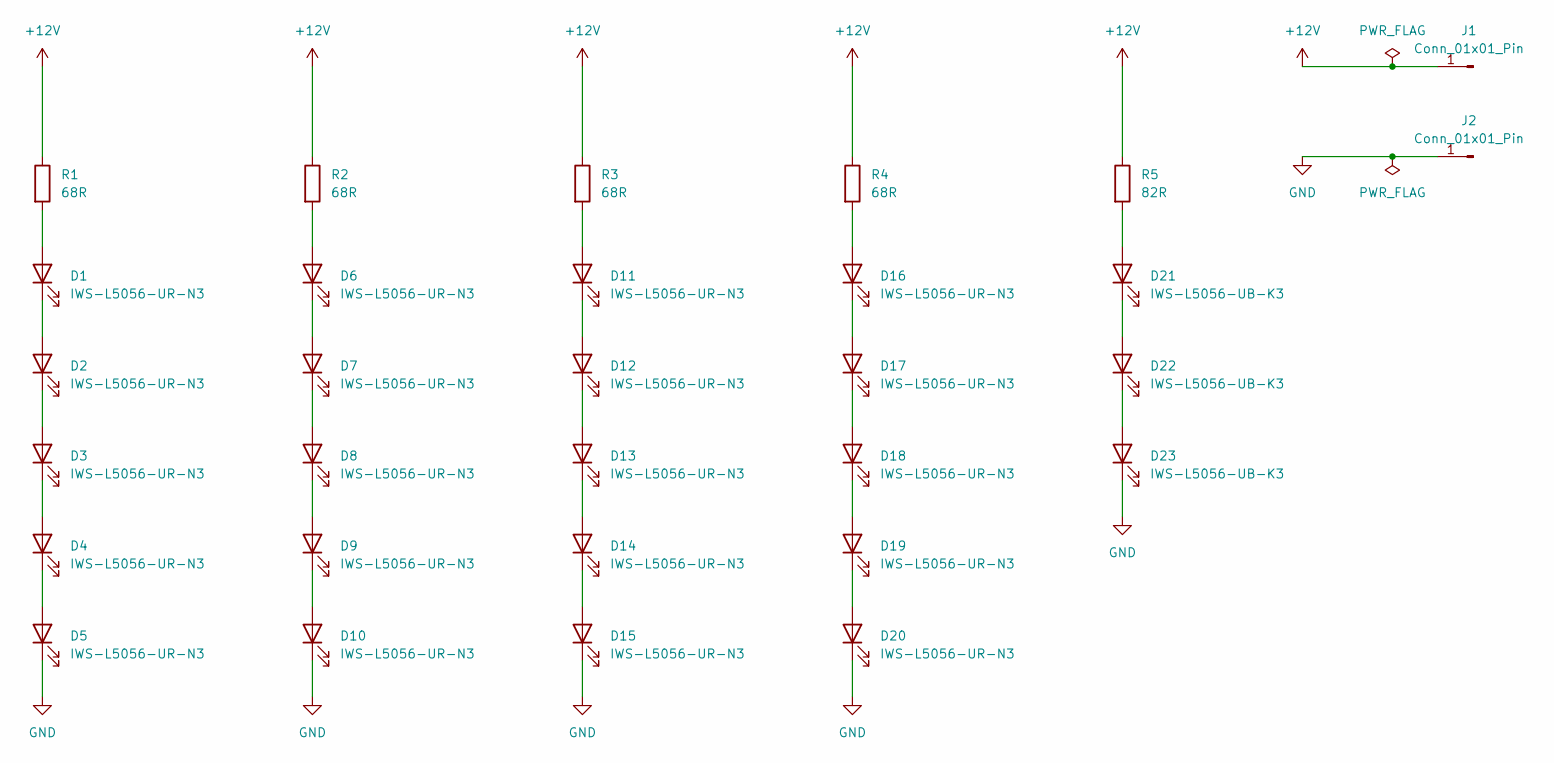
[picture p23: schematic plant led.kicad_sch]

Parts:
D1, D2, D3, D4, D5, D6, D7, D8, D9, D10, D11, D12, D13, D14, D15, D16, D17, D18, D19, D20: IWS-L5056-UR-N3; LED_5050_IWS_L5056_UR_N3
D21, D22, D23: IWS-L5056-UB-K3; LED_5050_IWS_L5056_UB_K3
J1, J2: Conn_01x01_Pin; Power_Solder_Pads_1P
R1, R2, R3, R4: 68R; R_2010_5025Metric
R5: 82R; R_2010_5025Metric

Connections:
+12V: J1.1 (Pin_1_1), R1.1, R2.1, R3.1, R4.1, R5.1
GND: D5.1 (K), D10.1 (K), D15.1 (K), D20.1 (K), D23.1 (K), J2.1 (Pin_1_1)
unnamed: D1.2 (A), R1.2
unnamed: D1.1 (K), D2.2 (A)
unnamed: D2.1 (K), D3.2 (A)
unnamed: D3.1 (K), D4.2 (A)
unnamed: D4.1 (K), D5.2 (A)
unnamed: D6.2 (A), R2.2
unnamed: D6.1 (K), D7.2 (A)
unnamed: D7.1 (K), D8.2 (A)
unnamed: D8.1 (K), D9.2 (A)
unnamed: D9.1 (K), D10.2 (A)
unnamed: D11.2 (A), R3.2
unnamed: D11.1 (K), D12.2 (A)
unnamed: D12.1 (K), D13.2 (A)
unnamed: D13.1 (K), D14.2 (A)
unnamed: D14.1 (K), D15.2 (A)
unnamed: D16.2 (A), R4.2
unnamed: D16.1 (K), D17.2 (A)
unnamed: D17.1 (K), D18.2 (A)
unnamed: D18.1 (K), D19.2 (A)
unnamed: D19.1 (K), D20.2 (A)
unnamed: D21.2 (A), R5.2
unnamed: D21.1 (K), D22.2 (A)
unnamed: D22.1 (K), D23.2 (A)

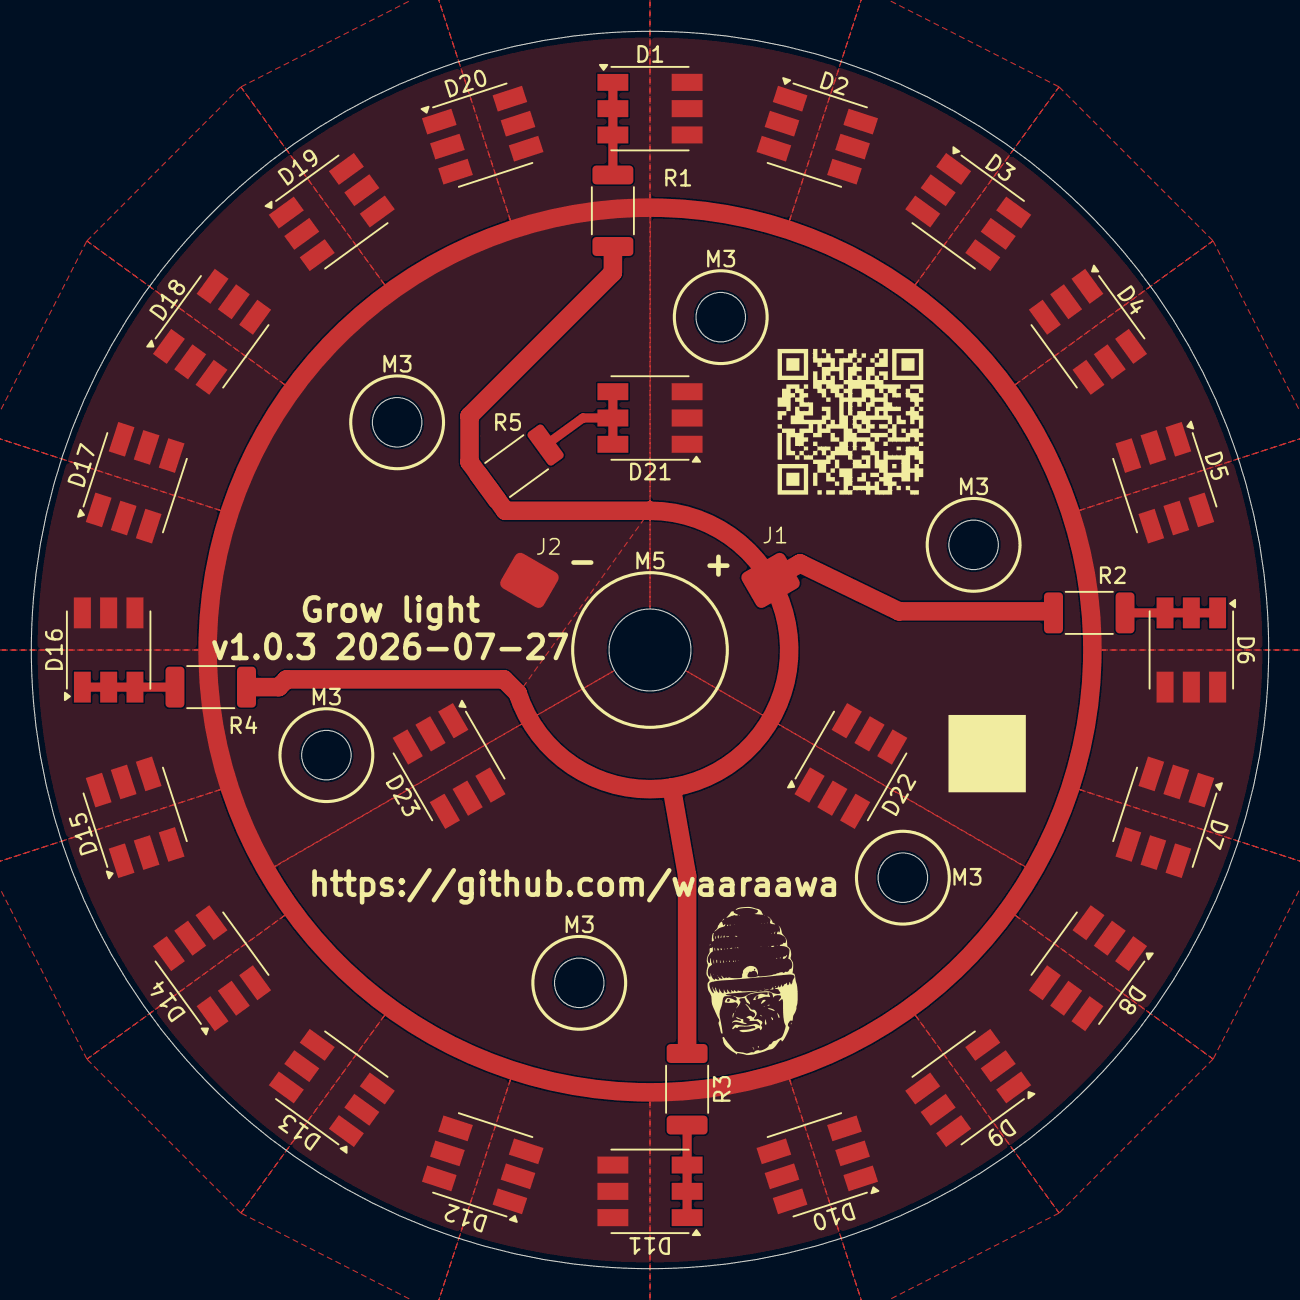
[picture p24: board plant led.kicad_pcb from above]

Board: 2 copper layers, 80.0 x 80.0 mm, 37 parts (0 on the bottom side), 25 nets.

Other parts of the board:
M3, M3#2, M3#3, M3#4, M3#5, M3#6: MountingHole_3.2mm_M3_DIN965
M5: MountingHole_5.3mm_M5_DIN965

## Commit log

2026-07-15 feat(pcb): add v1.0.2 aluminum MCPCB design
    - add the KiCad schematic and F.Cu-only board layout
    - document parts, assembly, safety, and project status
    - include component datasheets and mechanical references
    - ignore local KiCad files and generated manufacturing outputs
    [plant led.kicad_pcb, plant led.kicad_sch]
2026-07-27 feat(pcb): add v1.0.3 silkscreen guides
    Add silkscreen rings around the mounting and cable holes.
    Document the current MCPCB design, project status, and preview images.
    [plant led.kicad_pcb]
2026-07-28 feat(pcb): add power polarity silkscreen labels
    [plant led.kicad_pcb]
2026-08-04 docs: add v1.0.2 build log and assembly photos
